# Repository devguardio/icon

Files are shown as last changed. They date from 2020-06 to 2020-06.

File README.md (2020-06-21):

ICON the internets RGB panel
-----------------------------

A  WIFI connected RGB panel you can directly program on your personal computer using javascript, golang, rust, C, C++, python, etc

Display stuff from afar without a cloud! The devguard carrier SDK allows direct peer to peer encrypted connection to the device over the internet.

Getting started
===============

1. Press the reset button to reset to factory settings
2. use the ESP Provision App to supply your wifi password
3. Scan the bardcode on your device to get the devguard carrier identity
4. run `carrier config auth <identity> auth add self "*"`
5. play with the example source code to display some pixels!

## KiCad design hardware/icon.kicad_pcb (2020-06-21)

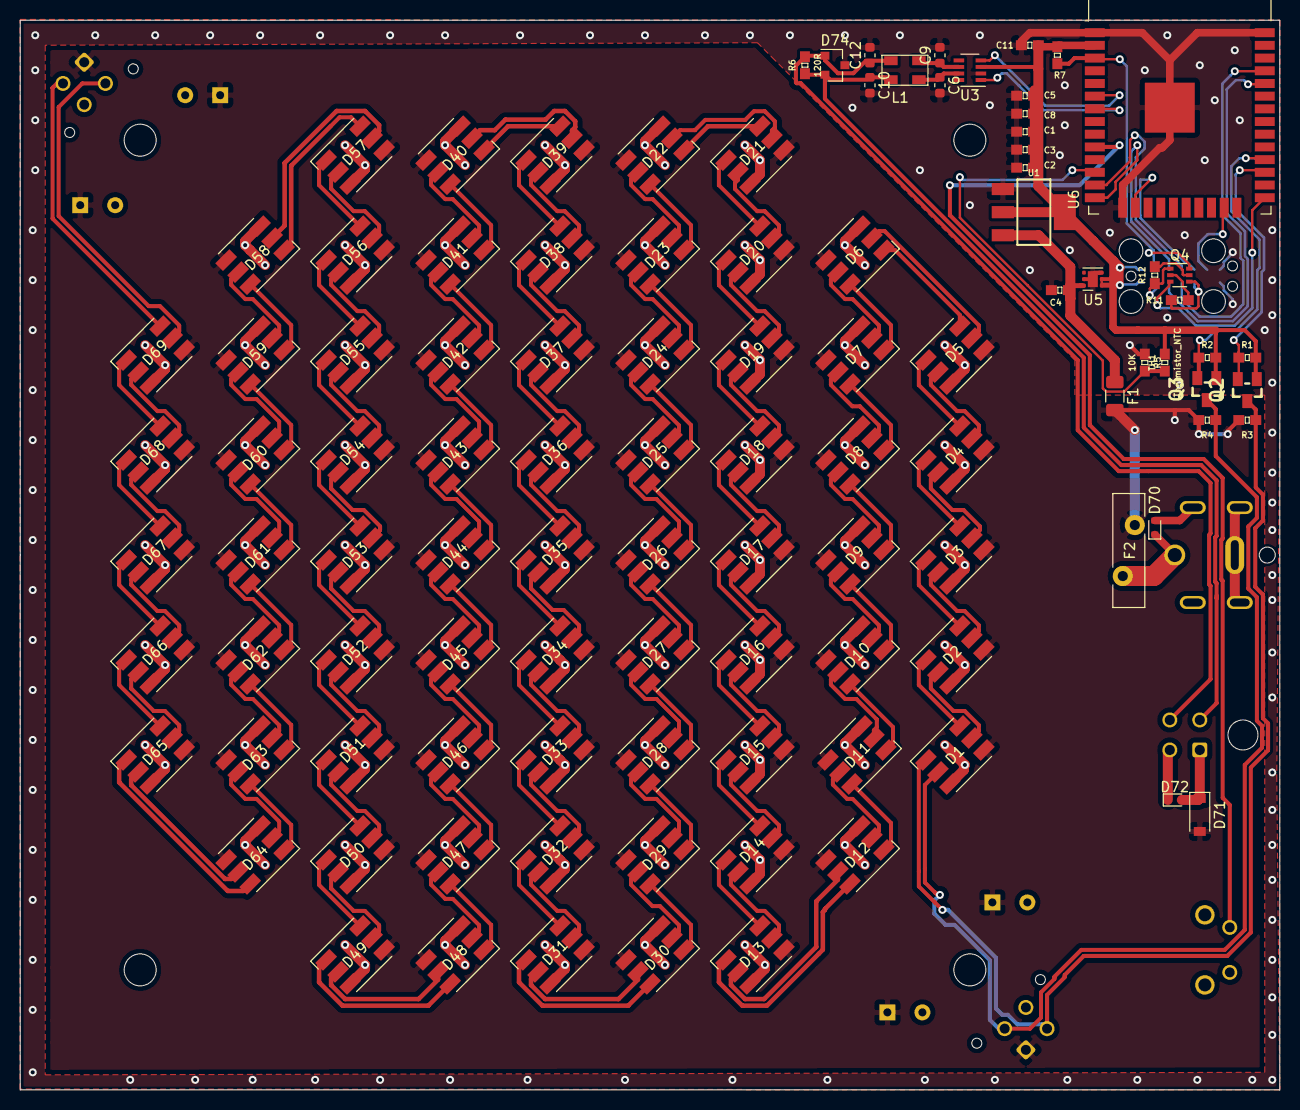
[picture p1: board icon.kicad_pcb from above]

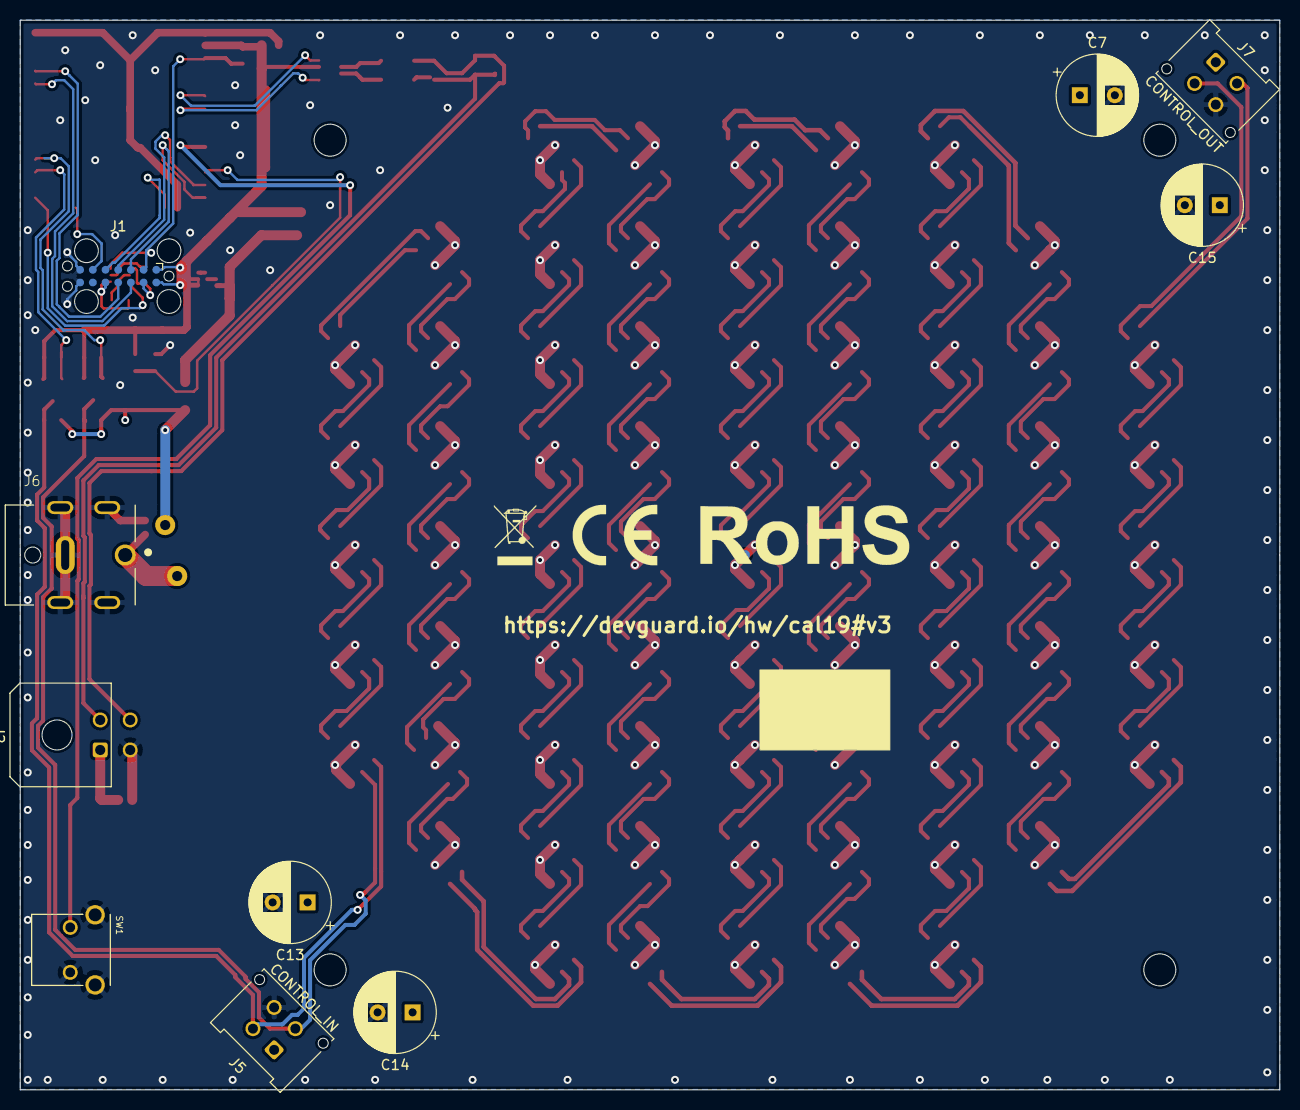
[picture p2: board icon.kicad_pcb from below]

Board: 2 copper layers, 126.0 x 107.0 mm, 122 parts (14 on the bottom side), 168 nets.

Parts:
C1, C2, C3, C5, C8, C11: 2.2uF; 0603
C4: 1uF; 0603
C6, C9, C10, C12: 56pf; C_0603_1608Metric
C7, C13, C14, C15: CP; CP_Radial_D8.0mm_P3.50mm
D1, D2, D3, D4, D5, D6, D7, D8, D9, D10, D11, D12, D13, D14, D15, D16, D17, D18, D19, D20, D21, D22, D23, D24, D25, D26, D27, D28, D29, D30, D31, D32, D33, D34, D35, D36, D37, D38, D39, D40, D41, D42, D43, D44, D45, D46, D47, D48, D49, D50, D51, D52, D53, D54, D55, D56, D57, D58, D59, D60, D61, D62, D63, D64, D65, D66, D67, D68, D69: APA102; LED_RGB_5050-6
D70: Transient Suppressor 7-8V clamp; D_SOD-523
D71: D_Schottky 3A; D_SOD-123
D72: Transient Suppressor; D_SOD-523
D74: SZNUP2105L; SOT-23
F1: PTC 0.5A; Fuse_1206_3216Metric
F2: 650-RGEF500; Fuse_Bourns_MF-RHT500
FID1: Fiducial; FIDUCIAL-1X2
H1, H2, H3, H4: MountingHole; MountingHole_3.2mm_M3
J1: UART; Tag-Connect_TC2070-IDC-FP_2x07_P1.27mm_Vertical
J2: Conn_02x02_Top_Bottom; Molex_Micro-Fit_3.0_43045-0400_2x02_P3.00mm_Horizontal
J5: CONTROL_IN; Molex_Micro-Fit_3.0_43045-0412_2x02_P3.00mm_Vertical
J6: PJ-082BH; CUI_PJ-082BH
J7: CONTROL_OUT; Molex_Micro-Fit_3.0_43045-0412_2x02_P3.00mm_Vertical
L1: PE-1210ACC110STS 11UH; PE-1210ACC
Q2, Q3: MOSFET-NCH-BSS138; SOT23-3
Q4: MBT3904DW1; SOT-363_SC-70-6
R1, R2, R3, R4, R5, R7, R11, R12: 10K; 0603
R6: 120R; 0603
SW1: SW_Push; SW_1825027-5
TH1: Thermistor_NTC; 0603
U1: AZ1117IH-3.3TRG; SOT223
U3: TCAN332; SOT-23-8
U5: 595-TLV76733DRVR; WSON-6-1EP_2x2mm_P0.65mm_EP1x1.6mm
U6: ESP32-WROOM-32D; ESP32-WROOM-32
X1: dummy; WEEE-Logo_4.2x6mm_SilkScreen
X2: dummy; RoHS-Logo_6mm_SilkScreen
X3: dummy; CE-Logo_8.5x6mm_SilkScreen

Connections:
5V: C7.1, C13.1, C14.1, C15.1, D1.4, D2.4, D3.4, D4.4, D5.4, D6.4, D7.4, D8.4, D9.4, D10.4, D11.4, D12.4, D13.4, D14.4, D15.4, D16.4, D17.4, D18.4, D19.4, D20.4, D21.4, D22.4, D23.4, D24.4, D25.4, D26.4, D27.4, D28.4, D29.4, D30.4, D31.4, D32.4, D33.4, D34.4, D35.4, D36.4, D37.4, D38.4, D39.4, D40.4, D41.4, D42.4, D43.4, D44.4, D45.4, D46.4, D47.4, D48.4, D49.4, D50.4, D51.4, D52.4, D53.4, D54.4, D55.4, D56.4, D57.4, D58.4, D59.4, D60.4, D61.4, D62.4, D63.4, D64.4, D65.4, D66.4, D67.4, D68.4, D69.4, D71.2, F1.2, F2.1, J5.1, J7.1, R3.2, R4.2
/c2+: C6.1, L1.2, U3.7
/c2-: C9.1, L1.1, U3.6
ADC_T: R5.2, TH1.1, U6.12
C0: D1.2, J5.3, Q3.3, R4.1
C1: D31.5, D32.2
CAN0+: C10.1, D74.2, J2.2, L1.3, R6.1
CAN0-: C12.1, D74.1, J2.4, L1.4, R6.2
CAN_RX: U3.4, U6.6
CAN_TX: U3.1, U6.7
CPU_BOOT: Q4.3, U6.25
CPU_ENABLE: J1.2, Q4.6, R7.1, U6.3
D0: D1.1, J5.2, Q2.3, R3.1
D1: D31.6, D32.1
FTDI_CTS: J1.13, Q4.1, R12.1
FTDI_DTR: J1.10, Q4.4, R11.1
FTDI_RXD: J1.11, U6.35
FTDI_TXD: J1.12, U6.34
GND: C1.2, C2.2, C3.2, C4.2, C5.2, C6.2, C7.2, C8.2, C9.2, C10.2, C11.2, C12.2, C13.2, C14.2, C15.2, D1.3, D2.3, D3.3, D4.3, D5.3, D6.3, D7.3, D8.3, D9.3, D10.3, D11.3, D12.3, D13.3, D14.3, D15.3, D16.3, D17.3, D18.3, D19.3, D20.3, D21.3, D22.3, D23.3, D24.3, D25.3, D26.3, D27.3, D28.3, D29.3, D30.3, D31.3, D32.3, D33.3, D34.3, D35.3, D36.3, D37.3, D38.3, D39.3, D40.3, D41.3, D42.3, D43.3, D44.3, D45.3, D46.3, D47.3, D48.3, D49.3, D50.3, D51.3, D52.3, D53.3, D54.3, D55.3, D56.3, D57.3, D58.3, D59.3, D60.3, D61.3, D62.3, D63.3, D64.3, D65.3, D66.3, D67.3, D68.3, D69.3, D70.2, D72.1, D74.3, J1.7, J1.8, J2.3, J5.4, J6.2, J6.3, J6.4, J6.5, J6.6, J7.4, R5.1, SW1.2, SW1.S1, SW1.S2, U1.1, U3.2, U5.3, U5.5, U5.7, U6.1, U6.15, U6.38, U6.39
JTAG_TCK: J1.5, U6.16
JTAG_TDI: J1.3, U6.14
JTAG_TDO: J1.6, U6.23
JTAG_TMS: J1.4, U6.13
LED_CLOCK: Q3.2, R2.1, U6.28
LED_DATA: Q2.2, R1.1, U6.27
unnamed: C4.1, F1.1, U1.3, U5.6
unnamed: D1.5, D2.2
unnamed: D1.6, D2.1
unnamed: D2.5, D3.2
unnamed: D2.6, D3.1
unnamed: D3.5, D4.2
unnamed: D3.6, D4.1
unnamed: D4.5, D5.2
unnamed: D4.6, D5.1
unnamed: D5.5, D6.2
unnamed: D5.6, D6.1
unnamed: D6.5, D7.2
unnamed: D6.6, D7.1
unnamed: D7.5, D8.2
unnamed: D7.6, D8.1
unnamed: D8.5, D9.2
unnamed: D8.6, D9.1
unnamed: D9.6, D10.1
unnamed: D9.5, D10.2
unnamed: D10.5, D11.2
unnamed: D10.6, D11.1
unnamed: D11.5, D12.2
unnamed: D11.6, D12.1
unnamed: D12.5, D13.2
unnamed: D12.6, D13.1
unnamed: D13.5, D14.2
unnamed: D13.6, D14.1
unnamed: D14.5, D15.2
unnamed: D14.6, D15.1
unnamed: D15.5, D16.2
unnamed: D15.6, D16.1
unnamed: D16.5, D17.2
unnamed: D16.6, D17.1
unnamed: D17.5, D18.2
unnamed: D17.6, D18.1
unnamed: D18.5, D19.2
unnamed: D18.6, D19.1
unnamed: D19.5, D20.2
unnamed: D19.6, D20.1
unnamed: D20.5, D21.2
unnamed: D20.6, D21.1
unnamed: D21.5, D22.2
unnamed: D21.6, D22.1
unnamed: D22.5, D23.2
unnamed: D22.6, D23.1
unnamed: D23.5, D24.2
unnamed: D23.6, D24.1
unnamed: D24.5, D25.2
unnamed: D24.6, D25.1
unnamed: D25.5, D26.2
unnamed: D25.6, D26.1
unnamed: D26.5, D27.2
unnamed: D26.6, D27.1
unnamed: D27.5, D28.2
unnamed: D27.6, D28.1
unnamed: D28.5, D29.2
unnamed: D28.6, D29.1
unnamed: D29.5, D30.2
unnamed: D29.6, D30.1
unnamed: D30.5, D31.2
unnamed: D30.6, D31.1
unnamed: D32.5, D33.2
unnamed: D32.6, D33.1
unnamed: D33.5, D34.2
unnamed: D33.6, D34.1
unnamed: D34.5, D35.2
unnamed: D34.6, D35.1
unnamed: D35.5, D36.2
unnamed: D35.6, D36.1
unnamed: D36.5, D37.2
unnamed: D36.6, D37.1
unnamed: D37.5, D38.2
unnamed: D37.6, D38.1
unnamed: D38.5, D39.2
unnamed: D38.6, D39.1
unnamed: D39.5, D40.2
unnamed: D39.6, D40.1
unnamed: D40.5, D41.2
unnamed: D40.6, D41.1
unnamed: D41.5, D42.2
unnamed: D41.6, D42.1
unnamed: D42.5, D43.2
unnamed: D42.6, D43.1
unnamed: D43.5, D44.2
unnamed: D43.6, D44.1
unnamed: D44.5, D45.2
unnamed: D44.6, D45.1
unnamed: D45.5, D46.2
unnamed: D45.6, D46.1
unnamed: D46.5, D47.2
unnamed: D46.6, D47.1
unnamed: D47.5, D48.2
unnamed: D47.6, D48.1
unnamed: D48.5, D49.2
unnamed: D48.6, D49.1
unnamed: D49.5, D50.2
unnamed: D49.6, D50.1
unnamed: D50.5, D51.2
unnamed: D50.6, D51.1
unnamed: D51.5, D52.2
unnamed: D51.6, D52.1
unnamed: D52.5, D53.2
unnamed: D52.6, D53.1
unnamed: D53.5, D54.2
unnamed: D53.6, D54.1
unnamed: D54.5, D55.2
unnamed: D54.6, D55.1
unnamed: D55.5, D56.2
unnamed: D55.6, D56.1
unnamed: D56.5, D57.2
unnamed: D56.6, D57.1
unnamed: D57.5, D58.2
unnamed: D57.6, D58.1
unnamed: D58.5, D59.2
unnamed: D58.6, D59.1
unnamed: D59.5, D60.2
unnamed: D59.6, D60.1
unnamed: D60.5, D61.2
unnamed: D60.6, D61.1
unnamed: D61.5, D62.2
unnamed: D61.6, D62.1
unnamed: D62.5, D63.2
unnamed: D62.6, D63.1
unnamed: D63.5, D64.2
unnamed: D63.6, D64.1
unnamed: D64.5, D65.2
unnamed: D64.6, D65.1
unnamed: D65.5, D66.2
unnamed: D65.6, D66.1
unnamed: D66.5, D67.2
unnamed: D66.6, D67.1
unnamed: D67.5, D68.2
unnamed: D67.6, D68.1
unnamed: D68.5, D69.2
unnamed: D68.6, D69.1
unnamed: D69.5, J7.3
unnamed: D69.6, J7.2
unnamed: D70.1, F2.2, J6.1
unnamed: D71.1, D72.2, J2.1
unnamed: Q4.2, R11.2
unnamed: Q4.5, R12.2
VDD: C1.1, C2.1, C3.1, C5.1, C8.1, C11.1, J1.1, J1.14, Q2.1, Q3.1, R1.2, R2.2, R7.2, TH1.2, U1.2, U1.4, U3.3, U5.1, U5.2, U6.2
softreset: SW1.1, U6.10
